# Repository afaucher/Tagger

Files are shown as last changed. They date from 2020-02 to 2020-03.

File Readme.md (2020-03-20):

# Tagger

A prototype for a laser tag system for use in RC.

Based on: https://github.com/afaucher/LazerTagHost

“Tagger” Copyright 2020 Alexander Faucher

Tagger is compatible but not affiliated with Nerf and Tiger brand Phoenix LTX guns and Laser Tag Team Ops (LTTO) guns.

# Build

The wiring is documented in the Fritzing project file.

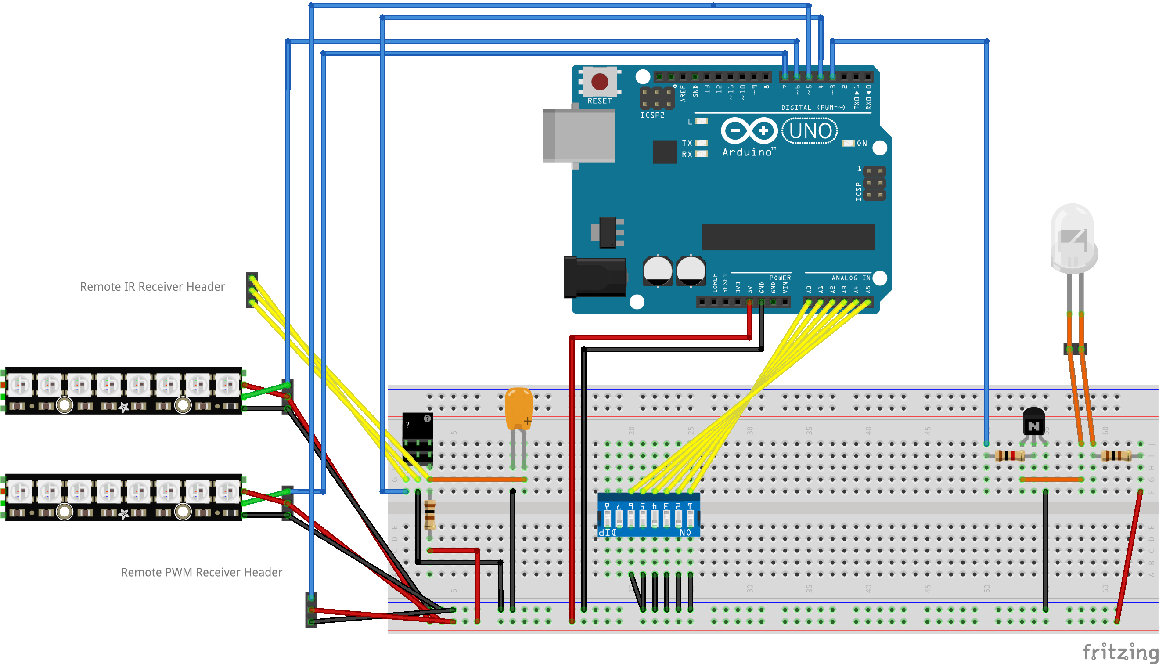
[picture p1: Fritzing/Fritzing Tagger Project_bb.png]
Breadboard


Things to note on the build:
* There are two 100Ω resistors that are identical in the layout.  This is intentional if these need to be adjusted independently later.  In particular, a 100Ω resistor is higher then ideal for the IR LED.
* PCB has not been manufactured yet so take it as-is.
* Headers are intended to be Servo 'J' connectors using right angle headers.
* '3 pin mystery part' is actually TSOP4138 38kHz Infrared Receiver (4.5-5.5V)
* IR led is TSOP6100 10 Degree Infrared Emitters

# Installation

This project has not been tested on an RC plane yet.  The intention is the following layout:

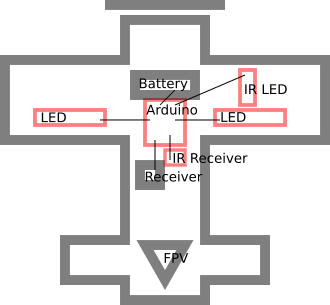
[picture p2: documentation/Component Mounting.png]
Layout


# Current Status

What works:
* Reading hits and taking damage.
* Tracking health.
* Player 'death'.
* Displaying hits (flash red), health (% green) & death (stay on white) on LED strip.
* Shooting
* Ammo tracking

What doesn't work yet:
* Dual LEDs strips, one for each wing.
* IR LED power amplification
* Configuring player / team via switches
* Powering via onboard battery
* All the physical parts for mounting on a plane.

# Bill of Materials

1. 1x Arduino Uno
  * https://www.sparkfun.com/products/11224
  * $22.95 each
1. 1x Capacitor (10uF, 16 volts)
  * TDK Multilayer Ceramic Capacitors (MLCC) – Leade
  * Mfg P/N: FK20X7R1C106K, Mouser P/N: 81—FK20X7R1C106K
  * $0.54 each
1. 1x 10 Degree 170mW Infrared Emitters
  * Vishay Infrared Emitters
  * Mfg P/N: TSAL6100, Mouser P/N: 782-TSAL6100
  * $0.44 each
1. 3x 38kHz Infrared Receiver (4.5-5.5V)
  * Vishay Infrared Receiver
  * Mfg P/N: TSOP4138, Mouser P/N: 782-TSOP4138
  * $1.16 each
1. 1x Tagger Board (rev1)
  * https://oshpark.com/shared_projects/CIAWogtW
  * $9.45 each
1. 1x Resistor (100ohms, ¼ watt, 5%)
  * Vishay Metal Film Resistors – Through Hole
  * Mfg P/N: CCF07100RJKE36, Mouser P/N: 71-CCF07100RJKE36
  * $0.04 each
1. 1x Resistor (47ohms, TBD)
  * TBD
1. 1x Resistor (1kohms, TBD)
  * TBD
1. 1x Transistor - NPN, 50V 800mA
  * https://www.sparkfun.com/products/13689
  * $0.50 each
1. 1x Breakaway right angle header
  * https://www.sparkfun.com/products/553
  * TBD
  * $1.95 each
1. 2x WS2812 5050 RGB Addressable
  * https://www.readymaderc.com/products/details/rmrc-fire-leds-ws2812-5050-rgb-addressable
  * $3.99 each
1. 1x Double Convex 50mm Lens, 100mm Focal Length
  * https://www.amazon.com/gp/product/B01HH8ECYC
  * $9.99 each
1. 1x Dip Switch - 8 Position
  * https://www.sparkfun.com/products/8034
  * $1.50

# References

Additional Thanks:
* Jim from LaserTagParts.com for his awesome public documentation: https://web.archive.org/web/20180706033641/http://www.lasertagparts.com/
* Ken Shirriff for his IR Remote code: http://www.righto.com/
* Kelvin Nelson for his PWM decoding code: https://create.arduino.cc/projecthub/kelvineyeone/read-pwm-decode-rc-receiver-input-and-apply-fail-safe-6b90eb
* FAST LED project
* Sparkfun for their great tutorials & good selection of Fritzing parts
* Ssaggers on Thingiverse for the inspiration on the lens mounting: [Thingiverse](https://www.thingiverse.com/thing:454862), [Blog](https://teslaandi.wordpress.com/2014/09/29/databullets-2-laser-tagger-handgun-mark-1/)

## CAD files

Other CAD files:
models/Case.3dm
models/LaserTag.3dm

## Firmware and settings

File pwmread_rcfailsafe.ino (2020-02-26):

/*  Kelvin Nelson 24/07/2019
 *  
 *  Pulse Width Modulation (PWM) decoding of RC Receiver with failsafe
 *  
 *  This code contains easy to use functions to measure square wave signals on any arduiuno pro mini, nano or uno pins, excluding A6 and A7.
 *  The code is intended to be used with RC receivers, but could also be used in most other PWM measurement applications as a direct replacement for pulseIn(PIN, HIGH). 
 *  (to date it hasn't been tested at a frequency greater than 1khz or on an arduino mega)
 *  
 *  An RC signal pulse can be converted from a pulse width duration (1000-2000uS) at each input pin into an -+100% (-+1.0) output for use in a sketch.
 *  The calibration for this conversion plus a failsafe setting can be set for each channel. (fail safe tolerances 10-330Hz and 500-2500uS). 
 *  
 *  The raw data for each pin can also be extracted, i.e. time of pulse, pulse width, frame length, duty and frequency.
 *  
 *  Set-up is quick, the organisation of this file is as follows:
 *  
 *    - Overview of the code
 *    - List of functions
 *    - How to use, including example sketches
 *    - User defined variables -> specify input pins, transmitter calibration, and failsafe.
 *    - Global variables and functions
 *  
 *  OVERVIEW OF THE CODE:
 *  
 *  The code enables pin change interrupts on the selected pins by setting the appropriate registers.
 *  
 *  A voltage change on any of the selected pins will trigger one of three Interrupt Service Routines depending on which register the pin belongs to.
 *    - ISR(PCINT0_vect), ISR(PCINT1_vect) or ISR(PCINT2_vect)
 *    
 *  Within each ISR the code determines which pin has changed, and makes a note of the time before returning back to the main loop().
 *  
 *  The time intervals between pin changes are used to calculate pulse width and frame length. 
 *  
 *  Flags are set by the ISR to indicate when new pulses are received.
 *  
 *  The Flags are then used to extract and process the data collected by each ISR.
 * 
 *  Although it's not exactly the same, this code follows similar principles to those explained in this video: https://youtu.be/bENjl1KQbvo
 * 
 */
// LIST OF FUNCTIONS:
// OUTPUT TYPE    NAME OF FUNCTION           NOTES

// void           setup_pwmRead()            initialise the PWM measurement using pin change interrupts

// RC RECEIVER DECODING
// boolean        RC_avail()                 returns a HIGH when new RC data is available
// float          RC_decode(channel number)  decodes the selected RC channel into the range +-100%, and applies a failsafe.
// void           print_RCpwm()              Prints the RC channel raw data to serial port (used for calibration).

// GENERIC PWM MEASUREMENTS
// boolean        PWM_read(channel number)   returns a HIGH when a new pulse has been detected on a particular channel. 
//                                           The function saves the pulse data to variables outside the interrupt routines
//                                           and must be called just before using the rest of PWM functions.
// unsigned long  PWM_time()                 returns the time at the start of pulse 
// float          PWM()                      returns the pulse width
// float          PWM_period()               returns the time between pulses
// float          PWM_freq()                 calculates the frequency
// float          PWM_duty()                 calculates the duty

// NOTE: PWM_read(CH) and RC_decode(CH) use the same flags to detect when new data is available, meaning data could be lost if both are used on the same channel at the same time.
// SUGESTION: if you want to use PWM_read(CH) to find the frame rate of an RC channel call it before RC_decode(CH). The output from RC_decode(CH) will then default to the failsafe.

// HOW TO USE, including example sketches

// under the "USER DEFINED VARIABLES" title in the code below:
//
//    Step 1: enter the input pins into the array pwmPIN[] = {}. 
//
//            - Any number of pins can be entered into pwmPIN[] (pins available 0 - 13 and A0 - A5)
//            - The pins do not need to be in numerical order, for example pwmPIN[] = {A0,5,6,10,8} for 5 channels, or pwmPIN[] = {A0,5} for 2 channels
//            - The first element in the array is the pin number for  "channel 1", and the second is the pin number for "channel 2"... etc.
//            - All pins connected to the RC receiver need to be at the start of the array. i.e. the first 2 channels could be RC inputs and the 3rd channel could be connected to another device like the echo pin of an ultrasonic sensor.
//
//    Step 2: if an RC receiver is connected to all of the inputs then set RC_inputs to 0, if not specify the number of channels connected to the receiver i.e. RC_inputs = 2;
//
//    Step 3: calibrate your transmitter by uploading a simple sketch with this .ino file included in the sketch folder, and print the raw PWM values to serial (alternatively copy and paste the functions needed into the sketch).
//            Using the info from the serial monitor manually update the values in arrays RC_min[], RC_mid[], RC_max[] to suit your transmitter (use full rates to get the best resolution).
        
//            an example sketch for printing the RC channel PWM data to serial. 
              /* 
              void setup()  {
                  setup_pwmRead();
                  Serial.begin(9600);
              }
              void loop() {
                  if(RC_avail()) print_RCpwm();
              }
               */

//    Step 4: Choose a failsafe position for each channel, in the range -1.0 to +1.0, and enter it into the array RC_failsafe[] = {}
//            Note: if you would like the arduino to respond to the loss of transmitter signal you may need to disable the failsafe feature on your receiver (if it has one).
//            an example sketch to check the operation of the failsafe, and for printing the calibrated channels to serial:
/* 
              unsigned long now;                        // timing variables to update data at a regular interval                  
              unsigned long rc_update;
              const int channels = 6;                   // specify the number of receiver channels
              float RC_in[channels];                    // an array to store the calibrated input from receiver 
              
              void setup()  {
                  setup_pwmRead();                      
                  Serial.begin(9600);
              }
              
              void loop()  {
                  now = millis();
                  
                  if(RC_avail() || now - rc_update > 25){   // if RC data is available or 25ms has passed since last update (adjust to suit frame rate of receiver)
                    
                    rc_update = now;                           
                    
                    //print_RCpwm();                        // uncommment to print raw data from receiver to serial
                    
                    for (int i = 0; i<channels; i++){       // run through each RC channel
                      int CH = i+1;
                      
                      RC_in[i] = RC_decode(CH);             // decode receiver channel and apply failsafe
                      
                      print_decimal2percentage(RC_in[i]);   // uncomment to print calibrated receiver input (+-100%) to serial       
                    }
                    Serial.println();                       // uncomment when printing calibrated receiver input to serial.
                  }
              }
               */

// EXAMPLE USE OF GENERIC PWM FUNCTIONS:
  /*
 // Print the pulse width of channel 1 to the serial monitor. 
 // This is equivelant to the using standard arduino pulseIn(pin, HIGH) function, but without blocking the code.
 
 if (PWM_read(1)){          // if a new pulse is detected on channel 1, print the pulse width to serial monitor.
   Serial.println(PWM());
 } 
  */
 // Or 
 /*
 // Print RC receiver frame length and frame rate
 
 if (PWM_read(1)){                                      // if a new pulse is detected on channel 1
   Serial.print(PWM_period(),0);Serial.print("uS ");     
   Serial.print(PWM_freq());Serial.println("Hz");
 }

 */

/*
 *  USER DEFINED VARIABLES (MODIFY TO SUIT YOUR APPLICATION)
 */
 
// PWM input pins, any of the following pins can be used: digital 0 - 13 or analog A0 - A5 
//TODO - Refactor to make library input
const int pwmPIN[]={5}; // an array to identify the PWM input pins (the array can be any length) 
                                  // first pin is channel 1, second is channel 2...etc

int RC_inputs = 0;                // The number of pins in pwmPIN that are connected to an RC receiver. Addition pins not connected to an RC receiver could be used for any other purpose i.e. detecting the echo pulse on an HC-SR04 ultrasonic distance sensor
                                  // When 0, it will automatically update to the number of pins specified in pwmPIN[] after calling setup_pwmRead().                                                
// Calibration of each RC channel:
 
// The arrays below are used to calibrate each RC channel into the range -1 to +1 so that servo direction, mixing, rates, sub trims...etc can be applied in sketch depending on application. 
// The arrays should be modified in order to calibrate the min, middle and max pulse durations to suit your transmitter (use max rates to get the best resolution). 
// FYI: the function print_PWM() will print the raw pulse width data for all the RC channels to the serial port.
// if the RC_min[], RC_mid[], RC_max[] are empty or have missing data the calibration will default to min 1000us, mid 1500us and max 2000us.

//SANWA 6CH 40MHz with corona RP6D1  
//                THR     RUD     PIT     BAL     SWITCH  SLIDER
//TODO - Calibrate
//int RC_min[6] = { 988,    1060,   976,    960,    1056,   1116};
//int RC_mid[6] = { 1472,   1446,   1424,   1398,   1374,   1460};
//int RC_max[6] = { 1800,   1816,   1796,   1764,   1876,   1796};
int RC_min[] = {};
int RC_mid[] = {};
int RC_max[] = {};

// fail safe positions
//TODO - Calibrate
//float RC_failsafe[] = {0.00, 0.00, 1, 0.00, -0.25, 0.00};
float RC_failsafe[] = {};
   
// enter a failsafe position (in the range of -+1) for each RC channel in case radio signal is lost
// if the array is the incorrect length for the number of RC channels, the failsafe will default to neutral i.e. 0. 
// The failsafe tolerances are: 10-330Hz & 500-2500us

/*
 *    GLOBAL PWM DECODE VARIABLES
 */

const int num_ch = 1;//sizeof(pwmPIN)/sizeof(int);  // calculate the number of input pins (or channels)
volatile int PW[num_ch];                        // an array to store pulsewidth measurements
volatile boolean prev_pinState[num_ch];         // an array used to determine whether a pin has gone low-high or high-low
volatile unsigned long pciTime;                 // the time of the current pin change interrupt
volatile unsigned long pwmTimer[num_ch];        // an array to store the start time of each PWM pulse

volatile boolean pwmFlag[num_ch];               // flag whenever new data is available on each pin
volatile boolean RC_data_rdy;                   // flag when all RC receiver channels have received a new pulse
unsigned long pwmPeriod[num_ch];                 // period, mirco sec, between two pulses on each pin

byte pwmPIN_reg[num_ch];                        // each of the input pins expressed as a position on it's associated port register
byte pwmPIN_port[num_ch];                       // identify which port each input pin belongs to (0 = PORTB, 1 = PORTC, 2 = PORTD)

const int size_RC_min = sizeof(RC_min) / sizeof(int);           // measure the size of the calibration and failsafe arrays
const int size_RC_mid = sizeof(RC_mid) / sizeof(int);
const int size_RC_max = sizeof(RC_max) / sizeof(int);
const int size_RC_failsafe = sizeof(RC_failsafe) / sizeof(float);

// FUNCTION USED TO TURN ON THE INTERRUPTS ON THE RELEVANT PINS
// code from http://playground.arduino.cc/Main/PinChangeInterrupt

void pciSetup(byte pin){
    *digitalPinToPCMSK(pin) |= bit (digitalPinToPCMSKbit(pin));  // enable pin
    PCIFR  |= bit (digitalPinToPCICRbit(pin));                   // clear any outstanding interrupt
    PCICR  |= bit (digitalPinToPCICRbit(pin));                   // enable interrupt for the group
}

// FUNCTION USED TO FIND THE PIN POSITION ON EACH PORT REGISTER: helps the interrupt service routines, ISR, run faster

void pwmPIN_to_port(){
  for (int i = 0; i < num_ch; i++){

    // determine which port and therefore ISR (PCINT0_vect, PCINT1_vect or PCINT2_vect) each pwmPIN belongs to.
                                                                  pwmPIN_port[i] = 1;    // pin belongs to PCINT1_vect (PORT C)
    if (pwmPIN[i] >= 0 && pwmPIN[i] <= 7)                         pwmPIN_port[i] = 2;    // pin belongs to PCINT2_vect (PORT D)
    else if (pwmPIN[i] >= 8 && pwmPIN[i] <= 13)                   pwmPIN_port[i] = 0;    // pin belongs to PCINT0_vect (PORT B)

    // covert the pin number (i.e. pin 11 or pin A0) to the pin position in the port register. There is most likely a better way of doing this using a macro...
    // (Reading the pin state directly from the port registers speeds up the code in the ISR)
    
    if(pwmPIN[i] == 0 || pwmPIN[i] == A0 || pwmPIN[i] == 8)         pwmPIN_reg[i] = 0b00000001;
    else if(pwmPIN[i] == 1 || pwmPIN[i] == A1 || pwmPIN[i] == 9)    pwmPIN_reg[i] = 0b00000010;
    else if(pwmPIN[i] == 2 || pwmPIN[i] == A2 || pwmPIN[i] == 10)   pwmPIN_reg[i] = 0b00000100;
    else if(pwmPIN[i] == 3 || pwmPIN[i] == A3 || pwmPIN[i] == 11)   pwmPIN_reg[i] = 0b00001000;
    else if(pwmPIN[i] == 4 || pwmPIN[i] == A4 || pwmPIN[i] == 12)   pwmPIN_reg[i] = 0b00010000;
    else if(pwmPIN[i] == 5 || pwmPIN[i] == A5 || pwmPIN[i] == 13)   pwmPIN_reg[i] = 0b00100000;
    else if(pwmPIN[i] == 6)                                         pwmPIN_reg[i] = 0b01000000;
    else if(pwmPIN[i] == 7)                                         pwmPIN_reg[i] = 0b10000000;
    
  }
}

// SETUP OF PIN CHANGE INTERRUPTS

void setup_pwmRead(){
  
  for(int i = 0; i < num_ch; i++){              // run through each input pin
    pciSetup(pwmPIN[i]);                        // enable pinchange interrupt for pin
  }
  pwmPIN_to_port();                             // determines the port for each input pin
                                                // pwmPIN_to_port() also coverts the pin number in pwmPIN[] (i.e. pin 11 or pin A0) to the pin position in the port register (i.e. 0b00000001) for use in the ISR.
  
  if(RC_inputs == 0 || RC_inputs > num_ch) RC_inputs = num_ch;    // define the number of pins connected to an RC receiver.                                          
} 

// INTERRUPT SERVICE ROUTINES (ISR) USED TO READ PWM INPUT

// the PCINT0_vect (B port register) reacts to any changes on pins D8-13.
// the PCINT1_vect (C port register)          ""        ""         A0-A5.
// the PCINT2_vect (D port register)          ""        ""         D0-7.

// port registers are used to speed up if statements in ISR code:
// https://www.arduino.cc/en/Reference/PortManipulation http://tronixstuff.com/2011/10/22/tutorial-arduino-port-manipulation/
// http://harperjiangnew.blogspot.co.uk/2013/05/arduino-port-manipulation-on-mega-2560.html


// READ INTERRUPTS ON PINS D8-D13: ISR routine detects which pin has changed, and returns PWM pulse width, and pulse repetition period.

ISR(PCINT0_vect){                                                 // this function will run if a pin change is detected on portB
  
  pciTime = micros();                                             // Record the time of the PIN change in microseconds

  for (int i = 0; i < num_ch; i++){                               // run through each of the channels
    if (pwmPIN_port[i] == 0){                                     // if the current channel belongs to portB
      
      if(prev_pinState[i] == 0 && PINB & pwmPIN_reg[i]){          // and the pin state has changed from LOW to HIGH (start of pulse)
        prev_pinState[i] = 1;                                     // record pin state
        pwmPeriod[i] = pciTime - pwmTimer[i];                     // calculate the time period, micro sec, between the current and previous pulse
        pwmTimer[i] = pciTime;                                    // record the start time of the current pulse
      }
      else if (prev_pinState[i] == 1 && !(PINB & pwmPIN_reg[i])){ // or the pin state has changed from HIGH to LOW (end of pulse)
        prev_pinState[i] = 0;                                     // record pin state
        PW[i] = pciTime - pwmTimer[i];                            // calculate the duration of the current pulse
        pwmFlag[i] = HIGH;                                        // flag that new data is available
        if(i+1 == RC_inputs) RC_data_rdy = HIGH;                  
      }
    }
  }
}

// READ INTERRUPTS ON PINS A0-A5: ISR routine detects which pin has changed, and returns PWM pulse width, and pulse repetition period.

ISR(PCINT1_vect){                                                 // this function will run if a pin change is detected on portC

  pciTime = micros();                                             // Record the time of the PIN change in microseconds

  for (int i = 0; i < num_ch; i++){                               // run through each of the channels
    if (pwmPIN_port[i] == 1){                                     // if the current channel belongs to portC
      
      if(prev_pinState[i] == 0 && PINC & pwmPIN_reg[i]){          // and the pin state has changed from LOW to HIGH (start of pulse)
        prev_pinState[i] = 1;                                     // record pin state
        pwmPeriod[i] = pciTime - pwmTimer[i];                     // calculate the time period, micro sec, between the current and previous pulse
        pwmTimer[i] = pciTime;                                    // record the start time of the current pulse
      }
      else if (prev_pinState[i] == 1 && !(PINC & pwmPIN_reg[i])){ // or the pin state has changed from HIGH to LOW (end of pulse)
        prev_pinState[i] = 0;                                     // record pin state
        PW[i] = pciTime - pwmTimer[i];                             // calculate the duration of the current pulse
        pwmFlag[i] = HIGH;                                         // flag that new data is available
        if(i+1 == RC_inputs) RC_data_rdy = HIGH;
      }
    }
  }
}

// READ INTERRUPTS ON PINS D0-7: ISR routine detects which pin has changed, and returns PWM pulse width, and pulse repetition period.

ISR(PCINT2_vect){                                                 // this function will run if a pin change is detected on portD

  pciTime = micros();                                             // Record the time of the PIN change in microseconds

  for (int i = 0; i < num_ch; i++){                               // run through each of the channels
    if (pwmPIN_port[i] == 2){                                     // if the current channel belongs to portD
      
      if(prev_pinState[i] == 0 && PIND & pwmPIN_reg[i]){          // and the pin state has changed from LOW to HIGH (start of pulse)
        prev_pinState[i] = 1;                                     // record pin state
        pwmPeriod[i] = pciTime - pwmTimer[i];                     // calculate the time period, micro sec, between the current and previous pulse
        pwmTimer[i] = pciTime;                                    // record the start time of the current pulse
      }
      else if (prev_pinState[i] == 1 && !(PIND & pwmPIN_reg[i])){ // or the pin state has changed from HIGH to LOW (end of pulse)
        prev_pinState[i] = 0;                                     // record pin state
        PW[i] = pciTime - pwmTimer[i];                            // calculate the duration of the current pulse
        pwmFlag[i] = HIGH;                                        // flag that new data is available
        if(i+1 == RC_inputs) RC_data_rdy = HIGH;
      }
    }
  }
}

/*
 *  RC OUTPUT FUNCTIONS
 */

 boolean RC_avail(){
    boolean avail = RC_data_rdy;
    RC_data_rdy = LOW;                          // reset the flag
    return avail;
    }

  float RC_decode(int CH){
  
  if(CH < 1 || CH > RC_inputs) return 0;     // if channel number is out of bounds return zero.
  
  int i = CH - 1;                     

  // determine the pulse width calibration for the RC channel. The default is 1000, 1500 and 2000us.
  
  int Min;
  if(CH <= size_RC_min) Min = RC_min[CH-1]; else Min = 1000;
  
  int Mid;
  if(CH <= size_RC_mid) Mid = RC_mid[CH-1]; else Mid = 1500;
  
  int Max;
  if(CH <= size_RC_max) Max = RC_max[CH-1]; else Max = 2000;

  float CH_output;
      
  if(FAILSAFE(CH) == HIGH){                         // If the RC channel is outside of failsafe tolerances (10-330hz and 500-2500uS)
      if(CH > size_RC_failsafe) CH_output = 0;      // and if no failsafe position has been defined, set output to neutral
      else CH_output = RC_failsafe[i];              // or if defined set the failsafe position 
  }
  else{                                             // If the RC signal is valid
    CH_output = calibrate(PW[i],Min,Mid,Max);       // calibrate the pulse width to the range -1 to 1.
  }
  return CH_output;                                 

  // The signal is mapped from a pulsewidth into the range of -1 to +1, using the user defined calibrate() function in this code. 

  // 0 represents neutral or center stick on the transmitter
  // 1 is full displacement of a control input is one direction (i.e full left rudder)
  // -1 is full displacement of the control input in the other direction (i.e. full right rudder)
}

/*
 *  Receiver Calibration
 */

 // NEED TO SPEED UP
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

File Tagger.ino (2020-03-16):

/*
   Based on LazerTagHost by Alex Faucher
   https://github.com/afaucher/LazerTagHost
   Based on IRremote by Ken Shirriff
   http://arcfn.com
*/

#include <IRremote.h>
#include <FastLED.h>
// https://github.com/thomasfredericks/Bounce2
#include <Bounce2.h>


// ==============
// LED Indicators
// ==============

#define NUM_LEDS_PER_STRIP 8
#define HEALTH_LED_PIN 6
#define AMMO_LED_PIN 7
CRGB leds[NUM_LEDS_PER_STRIP * 2];

// ==============
// IR State
// ==============

#define RECV_PIN 4
//Note: This pin is hardcoded into IRRemote
#define IR_TX_PIN 3

IRrecv irrecv(RECV_PIN);
IRsend irsend;

decode_results results;

// ==============
// PWM Receiver State
// ==============

//https://create.arduino.cc/projecthub/kelvineyeone/read-pwm-decode-rc-receiver-input-and-apply-fail-safe-6b90eb
#define NUMBER_RC_CHANNELS 1
#define TRIGGER_CHANNEL 0
//Setup: You must adjust the range/tolerance value for the channel you choose.
#define RECEIVER_TRIGGER_TOLERANCE_PERCENT 0.2f
#define TRIGGER_RANGE_VALUE 0.5f
#define RECEIVER_UPDATE_PERIOD_MILLIS 100
//Note: Pin 5 is hardcoded in pwmread_rcfailsafe

struct RcReceiver {
  uint32_t rc_update;
  float RC_in[NUMBER_RC_CHANNELS];                    // an array to store the calibrated input from receiver
};

RcReceiver rcReceiver = {};

// ==============
// Game State
// ==============

#define MAX_LIFE 16
//TODO - Count need to be switched to millis
#define HIT_COUNTDOWN_COUNT 10000
#define MAX_AMMO 50
#define SHOT_COOLDOWN_MILLIS 1000

struct GameState {
  uint8_t life; //[0-MAX_LIFE] where 0 is dead
  //These are limited to ranges for LTTO/LTX
  uint8_t teamId; //Solo: [0] Team: [1-3]
  uint8_t playerId; //[0-7]
  uint16_t hitCountdown; //If > 0, we have been hit
  uint8_t ammo;
  uint32_t lastShotFiredTimeMillis; //Zero if not in cooldown
};

GameState gameState = { MAX_LIFE, 0, 0, 0, MAX_AMMO };

// ==============
// Input State
// ==============

struct InputState {
  boolean triggerPulled;
  boolean resetGame;
  boolean hit;
  uint8_t hitDamage;
};

InputState inputState = { false, false, false };

// ==============
// Stats
// ==============

struct Stats {
  uint16_t hits;
  uint16_t hitsIgnoredDuringCountdown;
  uint16_t unknownIrPacket;
  uint16_t ledUpdates;
  uint16_t shotsFired;
};

Stats stats;

// ==============
// Buttons
// ==============

#define HIT_BUTTON_PIN A0
#define TRIGGER_BUTTON_PIN A1
#define DEBOUNCE_INTERVAL_MS 100

struct Buttons {
  Bounce hitButton;
  Bounce triggerButton;
};

Buttons buttons;

// Dumps out the decode_results structure.
// Call this after IRrecv::decode()
// void * to work around compiler issue
//void dump(void *v) {
//  decode_results *results = (decode_results *)v
void dump(decode_results *results) {
  uint8_t count = results->rawlen;
  if (results->decode_type == UNKNOWN) {
    Serial.println(F("Could not decode message"));
  }
  else {
    if (results->decode_type == PHOENIX_LTX) {
      Serial.print(F("LTX: "));
    }
    else if (results->decode_type == LAZER_TAG_TEAM_OPS) {
      Serial.print(F("LTTO: "));
    }
    Serial.print(results->value, HEX);
    Serial.print(F(", "));
    Serial.println(results->bits, DEC);
  }
  Serial.print(F("Raw ("));
  Serial.print(count, DEC);
  Serial.print(F("): "));

  for (uint8_t i = 0; i < count; i++) {
    if ((i % 2) == 1) {
      Serial.print(results->rawbuf[i]*USECPERTICK, DEC);
    }
    else {
      Serial.print(-(int)results->rawbuf[i]*USECPERTICK, DEC);
    }
    Serial.print(F(" "));
  }
  Serial.println();
}

void setup()
{
  //Start IR TX
  pinMode(IR_TX_PIN, OUTPUT);
  digitalWrite(IR_TX_PIN, LOW);

  // Setup Button Input
  buttons.hitButton.attach(HIT_BUTTON_PIN, INPUT_PULLUP);
  buttons.hitButton.interval(DEBOUNCE_INTERVAL_MS);
  buttons.triggerButton.attach(TRIGGER_BUTTON_PIN, INPUT_PULLUP);
  buttons.triggerButton.interval(DEBOUNCE_INTERVAL_MS);

  // Start the USB Serial
  Serial.begin(115200);
  Serial.println(F("Start"));
  // Start the IR receiver
  irrecv.enableIRIn();
  // Start the PWM RC receiver
  setup_pwmRead();
  // Setup LEDs
  // Note: The decision to seperate these was based on the wiring being easier.  This can be
  // refactored to support one long continous strip if needed.
  FastLED.addLeds<NEOPIXEL, HEALTH_LED_PIN>(leds, 0, NUM_LEDS_PER_STRIP);
  FastLED.addLeds<NEOPIXEL, AMMO_LED_PIN>(leds, NUM_LEDS_PER_STRIP, NUM_LEDS_PER_STRIP);
  setupLedValuesNow();
  // Duemilanove 5v regulator is only rated to 500mA on USB, which also powers the board.
  // Keep a conservative limit here.  Adjust if you know your board can drive higher current.
  FastLED.setMaxPowerInVoltsAndMilliamps(5, 100);
  updateLedValuesNow();
}

void shoot(uint16_t team, uint16_t player, uint16_t damage) {
  //Damage is encoded 0-3 for damage range [1-4]
  damage--;
  uint16_t data = ((team & 0x03) << 5)
                  | ((player & 0x07) << 2)
                  | (damage & 0x02);
  irsend.sendPHOENIX_LTX(data, 7);
  irrecv.enableIRIn();
  irrecv.resume();
}

//Update the LED state from the current game state
//Does not refresh the LEDs
void updateLedValues() {
  //HEALTH STRIP
  uint8_t healthPerLed = MAX_LIFE / NUM_LEDS_PER_STRIP;
  for (uint8_t i = 0; i < NUM_LEDS_PER_STRIP; i++) {
    //The order here defines precidence for which rule controls the output
    if (gameState.life == 0) { //Player Death
      leds[i] = CRGB::White;
    } else if (gameState.hitCountdown > 0) { //Hit Indicator
      leds[i] = CRGB::Red;
    } else { //Show Health
      if (i * healthPerLed < gameState.life) {
        //Note: Partial health can be indicated by blinking the last element
        leds[i] = CRGB::Green;
      } else {
        leds[i] = CRGB::Black;
      }
    }
  }
  //AMMO STRIP
  uint8_t ammoPerLed = MAX_AMMO / NUM_LEDS_PER_STRIP;
  for (uint8_t i = NUM_LEDS_PER_STRIP; i < NUM_LEDS_PER_STRIP * 2; i++) {
    //The order here defines precidence for which rule controls the output
    if (gameState.life == 0) { //Player Death
      leds[i] = CRGB::White;
    } else if (gameState.hitCountdown > 0) { //Hit Indicator
      leds[i] = CRGB::Red;
    } else { //Show Ammo & Shot indicator
      if ((i - NUM_LEDS_PER_STRIP) * ammoPerLed < gameState.ammo) {
        if (gameState.lastShotFiredTimeMillis > 0 && gameState.ammo > 0) { //Shot Indicator
          //Give an indication while firing by making ammo orange
          leds[i] = CRGB::Orange;
        } else { //Ammo indicator
          leds[i] = CRGB::Blue;
        }
      } else {
        leds[i] = CRGB::Black;
      }
    }
  }
}

//Initialize LEDs to a neutral value to diagnose any initialization issues
void setupLedValuesNow() {
  for (uint8_t i = 0; i < NUM_LEDS_PER_STRIP * 2; i++) {
    leds[i] = CRGB::Grey;
  }
  FastLED.show();
  stats.ledUpdates++;
}

void updateLedValuesNow() {
  updateLedValues();
  FastLED.show();
  stats.ledUpdates++;
}
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

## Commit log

2020-02-13 Button driven tagger.
    Led health status.
    Button causes hit. Cooldown counter on hit. Deducts life.
    Led flashes on hit.
    Most of the rest of the code is stubbed or disabled.
2020-02-14 Integrated IR receiver.
    I had to disable the led duty cycle as it was interrupting the IR sensor polling.
    I hooked up hits and did minimal parsing of the LTX packets.
    You can shoot it now and it flashes the hit indicator and drains life.
2020-02-21 Working with RC receiver.
    I integrated a small library for reading PWM data from an RC receiver that includes a failsafe feature. The library itself is not modular and hardcoded but it works for reading a single channel. You can now initiate pulling the trigger by putting an RC channel at the midpoint (1500).
    See: https://create.arduino.cc/projecthub/kelvineyeone/read-pwm-decode-rc-receiver-input-and-apply-fail-safe-6b90eb
    [Tagger.ino, pwmread_rcfailsafe.ino]
2020-02-26 Reduce memory pressure by cleaning up storage.
    Added untested ammo and firing support. Doesn't work yet.
    [Tagger.ino, pwmread_rcfailsafe.ino]
2020-02-27 Updated pin mappings to be more dense to match PCB layout. Tested shooting successfully.
    I created a layout in Fritzing (not included here yet) that maps everything out and I adjusted the pin mapping in code to match. The only divergance now is swapping IR TX with PWM Receiver input as the IR Remote library has some hardcoded constants for pin3 that are not obvious changes.
    I tested with an LTX gun and I was able to use an RC transmitter to cause the board to both shoot via throttle channel and be shot by the gun. The issue with pin 3 was the problem on the first test.
    [Tagger.ino]
2020-02-27 Include fritzing PCB layout & docs.
    [Fritzing Tagger Project.fzz]
2020-02-27 Updated PCB layout with small tweaks.
    [Fritzing Tagger Project.fzz]
2020-03-02 Fix buttons.
    Integrated Bounce2 to debounce presses.
    Fixed issue where IR/PWM conflicted with button presses. Uses |= now.
    Cleanup of misc comments.
    [Tagger.ino]
2020-03-02 Added lens mount 3d model and PCB logo.
    [LaserTag.3dm]
2020-03-04 Added BOM
2020-03-04 Fix BOM numbering
2020-03-16 Add ammo indicator LEDs.
2020-03-20 Added thanks for lens holder idea.
2020-03-27 Updated 3d models. Includes case.
    [Case.3dm, LaserTag.3dm]
